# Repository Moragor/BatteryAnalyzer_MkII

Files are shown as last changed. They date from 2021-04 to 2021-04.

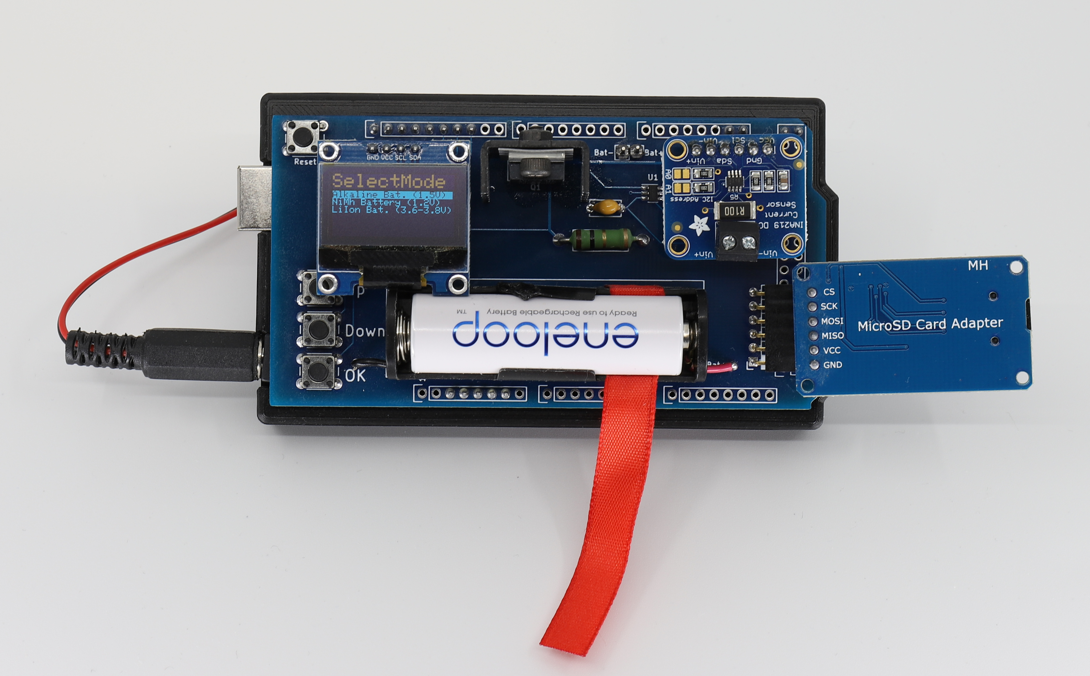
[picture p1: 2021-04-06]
pictures/Bat_mk2_1.JPG

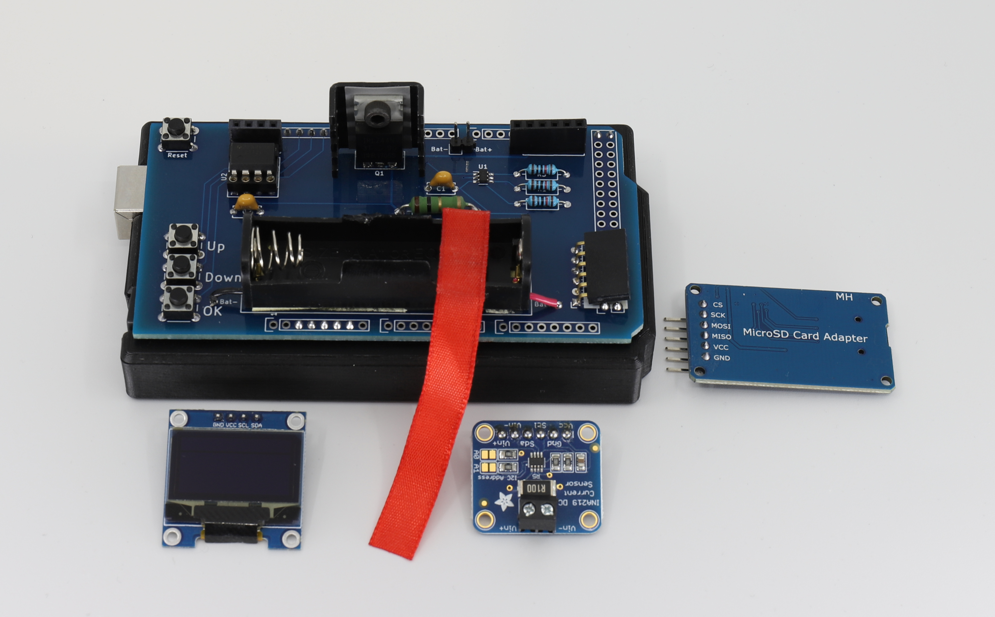
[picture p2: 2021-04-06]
pictures/Bat_mk2_4.JPG

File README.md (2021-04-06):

# BatteryAnalyzer_MkII
Updated Version of the battery analyzer, now with constant current testing instead of fixed resistors.

## Features:
- Selectable test current
- Support for Alkaline/LiFeS2, NiMh and Li-Ion/LiPo (1S) batteries
- Optional datalogging for voltage, current, power, capacity and energy with .csv output on microSD card

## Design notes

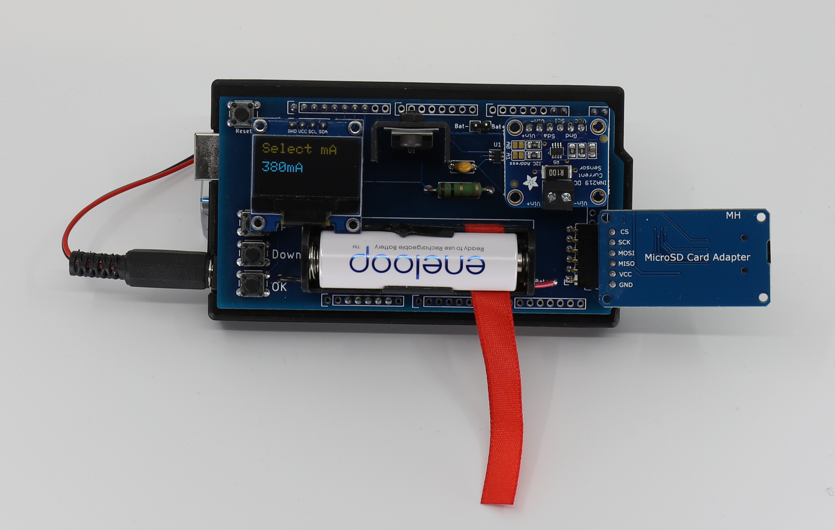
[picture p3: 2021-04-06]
pictures/Bat_mk2_2.JPG

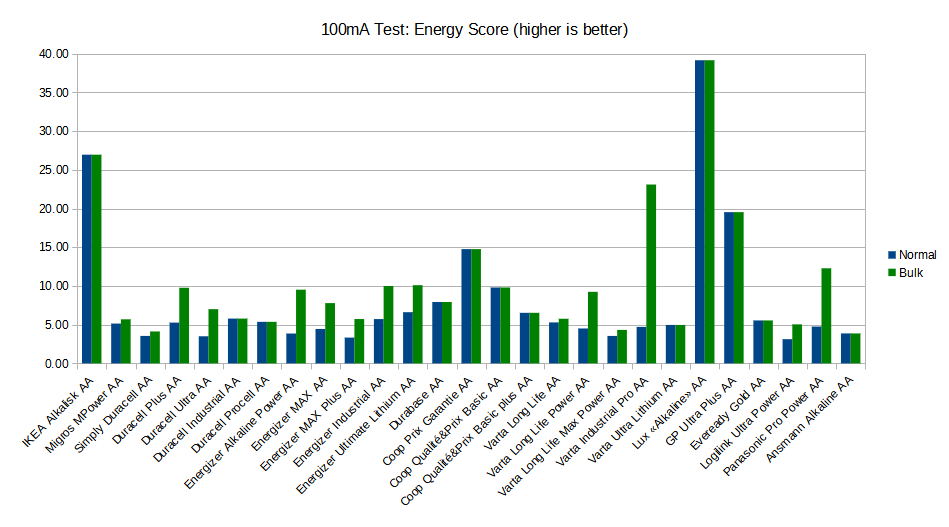
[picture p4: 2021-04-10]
tables and graphs/100mA_Score.png

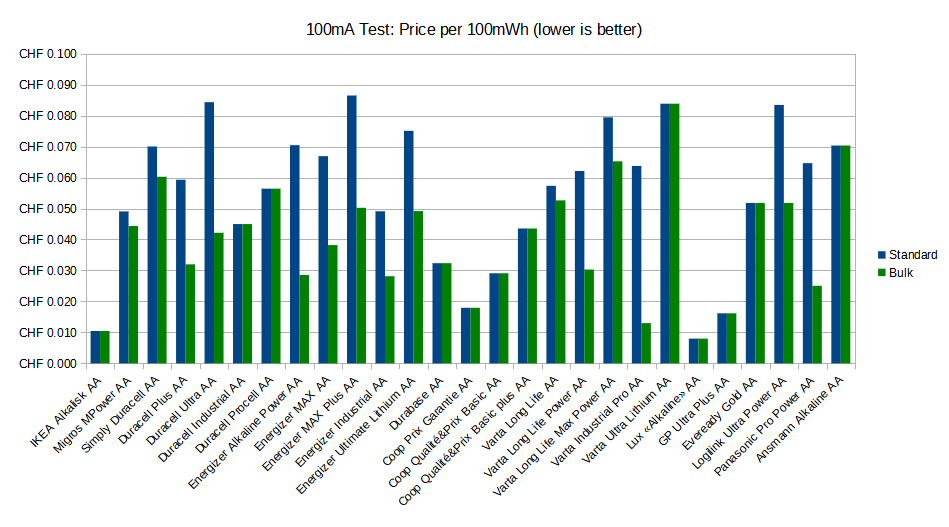
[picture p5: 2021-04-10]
tables and graphs/100mA_PpmWh.png

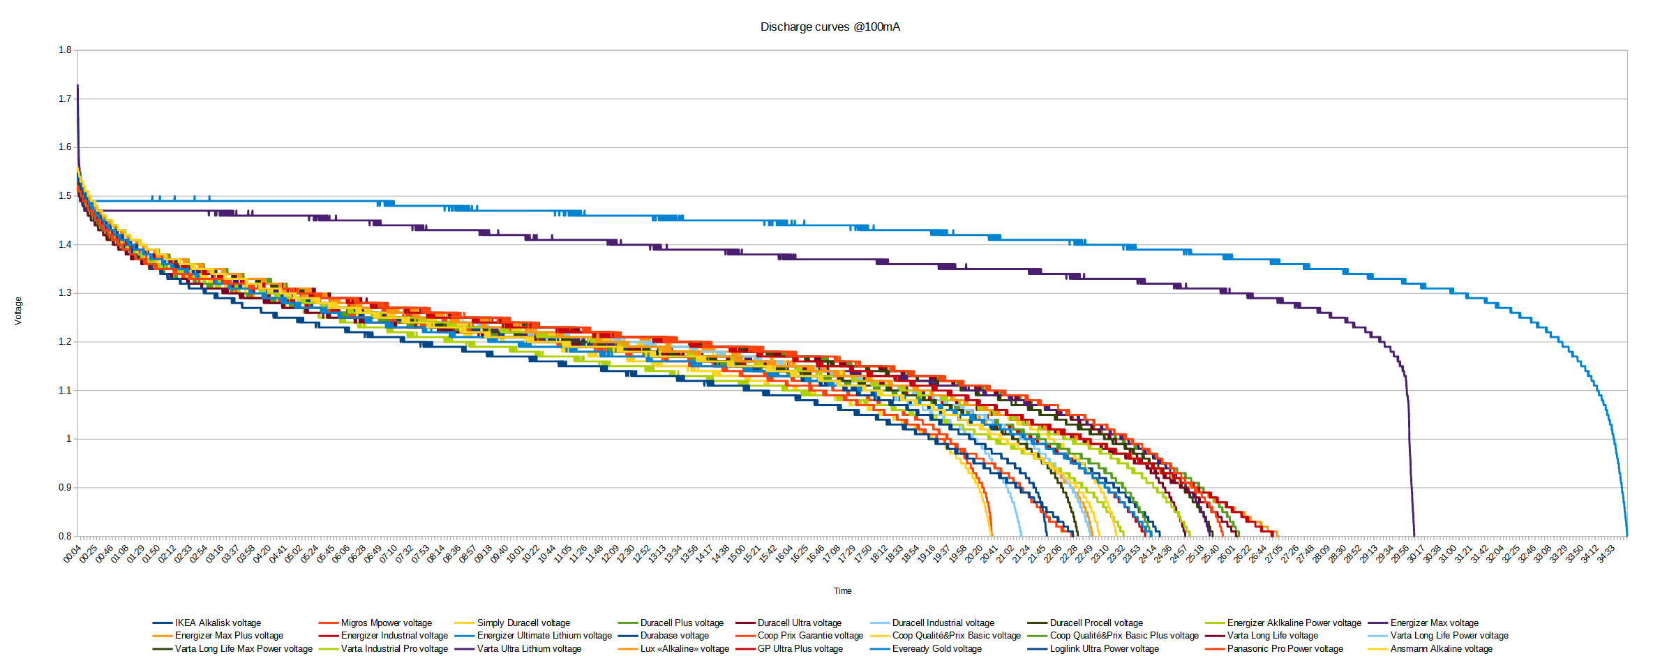
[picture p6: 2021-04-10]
tables and graphs/Discharge_curve_100mA.png

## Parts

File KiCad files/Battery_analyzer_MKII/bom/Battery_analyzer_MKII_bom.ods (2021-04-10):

Reference | Quantity | Value | Footprint | MPN | Digikey part number | Link
BT1 | 1 | AA_Bat_holder | MyComponents:AA_Battery_holder_L57mm_W17mm | 2461 | 36-2461-ND | https://www.digikey.ch/product-detail/de/keystone-electronics/2461/36-2461-ND/303810
C1 C2 | 2 | 1.0µF | MyComponents:C_Disc_D5.5mm_W2.7mm_P5.5mm | C333C105K5R5TA | 399-13915-ND | https://www.digikey.ch/product-detail/de/kemet/C333C105K5R5TA/399-13915-ND/6562326
J1 | 1 | Ext_bat_in | Connector_PinHeader_2.54mm:PinHeader_1x02_P2.54mm_Vertical | PREC002SAAN-RC | S1012EC-02-ND | https://www.digikey.ch/product-detail/de/sullins-connector-solutions/PREC002SAAN-RC/S1012EC-02-ND/2774852
J2 | 1 | OLED | Connector_PinSocket_2.54mm:PinSocket_1x04_P2.54mm_Vertical | SSW-104-01-T-S | SAM1213-04-ND | https://www.digikey.ch/product-detail/de/samtec-inc/SSW-104-01-T-S/SAM1213-04-ND/1112301
J3 | 1 | SD | Connector_PinSocket_2.54mm:PinSocket_1x06_P2.54mm_Horizontal | SSQ-106-02-T-S-RA | SAM1195-06-ND | https://www.digikey.ch/product-detail/de/samtec-inc/SSQ-106-02-T-S-RA/SAM1195-06-ND/1111406
J4 | 1 | INA291 | Connector_PinSocket_2.54mm:PinSocket_1x06_P2.54mm_Vertical | RS1-06-G | 2057-RS1-06-G-ND | https://www.digikey.ch/product-detail/de/adam-tech/RS1-06-G/2057-RS1-06-G-ND/9832050
P1 | 1 | Power | Connector_PinHeader_2.54mm:PinHeader_1x08_P2.54mm_Vertical | PH1-08-UA | 2057-PH1-08-UA-ND | https://www.digikey.ch/product-detail/de/adam-tech/PH1-08-UA/2057-PH1-08-UA-ND/9830442
P2 P3 | 2 | Analog | Connector_PinHeader_2.54mm:PinHeader_1x08_P2.54mm_Vertical | PH1-08-UA | 2057-PH1-08-UA-ND | https://www.digikey.ch/product-detail/de/adam-tech/PH1-08-UA/2057-PH1-08-UA-ND/9830442
P4 | 1 | Digital | Connector_PinHeader_2.54mm:PinHeader_2x18_P2.54mm_Vertical | PREC018DAAN-RC | S2012EC-18-ND | https://www.digikey.ch/product-detail/de/sullins-connector-solutions/PREC018DAAN-RC/S2012EC-18-ND/2774876
P5 | 1 | PWM | Connector_PinHeader_2.54mm:PinHeader_1x10_P2.54mm_Vertical | PH1-10-UA | 2057-PH1-10-UA-ND | https://www.digikey.ch/product-detail/de/adam-tech/PH1-10-UA/2057-PH1-10-UA-ND/9830653
P6 | 1 | PWM | Connector_PinHeader_2.54mm:PinHeader_1x08_P2.54mm_Vertical | PH1-08-UA | 2057-PH1-08-UA-ND | https://www.digikey.ch/product-detail/de/adam-tech/PH1-08-UA/2057-PH1-08-UA-ND/9830442
P7 | 1 | Communication | Connector_PinHeader_2.54mm:PinHeader_1x08_P2.54mm_Vertical | PH1-08-UA | 2057-PH1-08-UA-ND | https://www.digikey.ch/product-detail/de/adam-tech/PH1-08-UA/2057-PH1-08-UA-ND/9830442
Q1 | 1 | IRLZ44N | Package_TO_SOT_THT:TO-220-3_Vertical | IRLZ44NPBF | IRLZ44NPBF-ND | https://www.digikey.ch/product-detail/de/infineon-technologies/IRLZ44NPBF/IRLZ44NPBF-ND/811808
R1 R2 R3 | 3 | 10k | Resistor_THT:R_Axial_DIN0207_L6.3mm_D2.5mm_P10.16mm_Horizontal | MFR-25FBF52-10K | 10.0KXBK-ND | https://www.digikey.ch/product-detail/de/yageo/MFR-25FBF52-10K/10-0KXBK-ND/13219
R4 | 1 | 1R 2W | Resistor_THT:R_Axial_DIN0411_L9.9mm_D3.6mm_P15.24mm_Horizontal | RSMF2JT1R00 | RSMF2JT1R00CT-ND | https://www.digikey.ch/product-detail/de/stackpole-electronics-inc/RSMF2JT1R00/RSMF2JT1R00CT-ND/2021849
SW1 | 1 | UpButton | Button_Switch_THT:SW_PUSH_6mm_H5mm | 1825910-6 | 450-1650-ND | https://www.digikey.ch/product-detail/de/te-connectivity-alcoswitch-switches/1825910-6/450-1650-ND/1632536
SW2 | 1 | DnButton | Button_Switch_THT:SW_PUSH_6mm_H5mm | 1825910-6 | 450-1650-ND | https://www.digikey.ch/product-detail/de/te-connectivity-alcoswitch-switches/1825910-6/450-1650-ND/1632536
SW3 | 1 | OkButton | Button_Switch_THT:SW_PUSH_6mm_H5mm | 1825910-6 | 450-1650-ND | https://www.digikey.ch/product-detail/de/te-connectivity-alcoswitch-switches/1825910-6/450-1650-ND/1632536
SW4 | 1 | ResetButton | Button_Switch_THT:SW_PUSH_6mm_H5mm | 1825910-6 | 450-1650-ND | https://www.digikey.ch/product-detail/de/te-connectivity-alcoswitch-switches/1825910-6/450-1650-ND/1632536
U1 | 1 | MCP4725A0T-E_CH | Package_TO_SOT_SMD:SOT-23-6_Handsoldering | MCP4725A0T-E/CH | MCP4725A0T-E/CHCT-ND | https://www.digikey.ch/product-detail/de/microchip-technology/MCP4725A0T-E-CH/MCP4725A0T-E-CHCT-ND/1817328
U2 | 1 | TLV2372 | Package_DIP:DIP-8_W7.62mm_Socket | TLV2372IP | 296-12219-5-ND | https://www.digikey.ch/products/de/integrated-circuits-ics/linear-amplifiers-instrumentation-op-amps-buffer-amps/687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
U2 | 1 | 8-pin IC socket (optional) | Package_DIP:DIP-8_W7.62mm_Socket | ICS-308-T | 2057-ICS-308-T-ND | https://www.digikey.ch/product-detail/de/adam-tech/ICS-308-T/2057-ICS-308-T-ND/9829299
 | 1 | 0.96inch OLED screen |  |  |  | https://www.aliexpress.com/item/32643950109.html
 | 1 | INA291 module |  | 904 | 1528-1168-ND | https://www.digikey.ch/product-detail/de/adafruit-industries-llc/904/1528-1168-ND/5353628
 | 1 | MicroSD card adapter |  |  |  | https://www.aliexpress.com/item/4000002592780.html
 | 1 | mMicro SD card |  |  |  | https://www.amazon.com/-/de/dp/B073K14CVB?psc=1
 | 1 | Arduino Mega 2560 |  | A000067 | 1050-1018-ND | https://www.digikey.ch/product-detail/de/arduino/A000067/1050-1018-ND/2639006
 | 1 | TO-220 Heatsink |  | 274-1AB | 345-1023-ND | https://www.digikey.ch/product-detail/de/wakefield-vette/274-1AB/345-1023-ND/340321

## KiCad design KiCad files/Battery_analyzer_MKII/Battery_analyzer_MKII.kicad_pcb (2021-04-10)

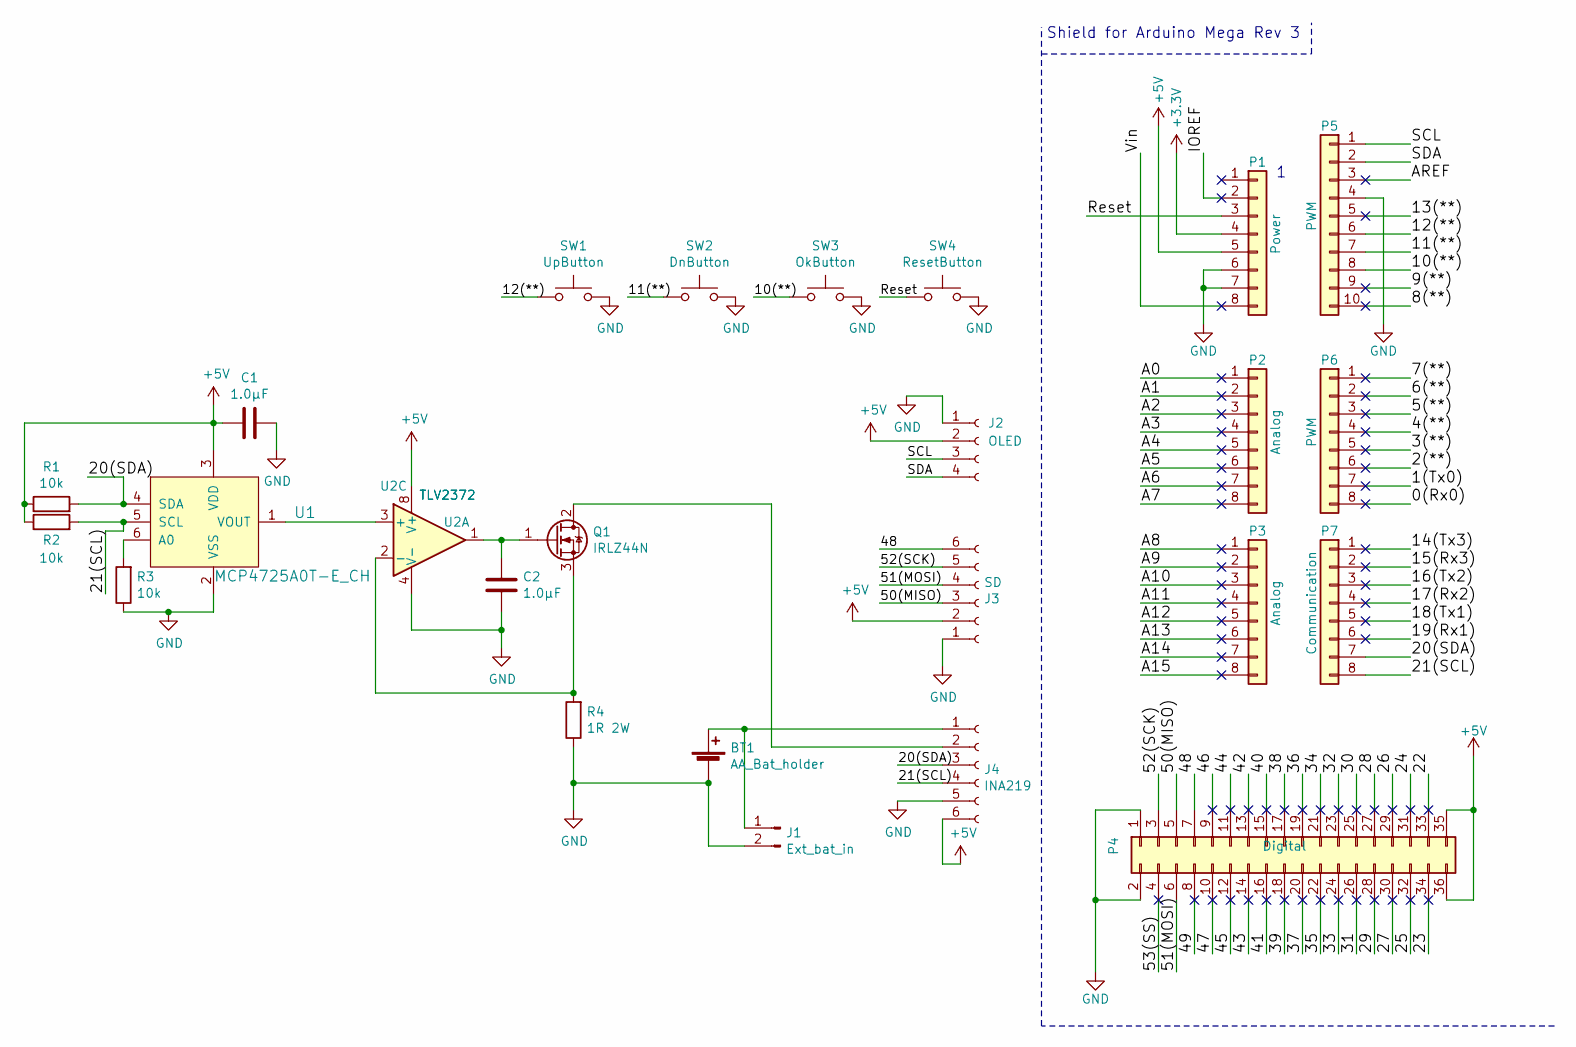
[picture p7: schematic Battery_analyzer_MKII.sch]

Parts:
BT1: AA_Bat_holder; AA_Battery_holder_L57mm_W17mm
C1, C2: 1.0µF; C_Disc_D5.5mm_W2.7mm_P5.5mm
J1: Ext_bat_in; PinHeader_1x02_P2.54mm_Vertical
J2: OLED; PinSocket_1x04_P2.54mm_Vertical
J3: SD; PinSocket_1x06_P2.54mm_Horizontal
J4: INA219; PinSocket_1x06_P2.54mm_Vertical
P1: Power; PinHeader_1x08_P2.54mm_Vertical
P2, P3: Analog; PinHeader_1x08_P2.54mm_Vertical
P4: Digital; PinHeader_2x18_P2.54mm_Vertical
P5: PWM; PinHeader_1x10_P2.54mm_Vertical
P6: PWM; PinHeader_1x08_P2.54mm_Vertical
P7: Communication; PinHeader_1x08_P2.54mm_Vertical
Q1: IRLZ44N; TO-220-3_Vertical
R1, R2, R3: 10k; R_Axial_DIN0207_L6.3mm_D2.5mm_P10.16mm_Horizontal
R4: 1R 2W; R_Axial_DIN0411_L9.9mm_D3.6mm_P15.24mm_Horizontal
SW1: UpButton; SW_PUSH_6mm_H5mm
SW2: DnButton; SW_PUSH_6mm_H5mm
SW3: OkButton; SW_PUSH_6mm_H5mm
SW4: ResetButton; SW_PUSH_6mm_H5mm
U1: MCP4725A0T-E_CH; SOT-23-6_Handsoldering; MPN MCP4725A0T-E/CH; Digi-Key_PN MCP4725A0T-E/CHCT-ND
U2: TLV2372; DIP-8_W7.62mm_Socket

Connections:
+3V3: P1.4
+5V: C1.2, J2.2, J3.2, J4.6, P1.5, P4.35, P4.36, R1.1, R2.1, U1.3 (VDD), U2.8 (V+)
/0(Rx0): P6.8
/1(Tx0): P6.7
/2(**): P6.6
/3(**): P6.5
/4(**): P6.4
/5(**): P6.3
/6(**): P6.2
/7(**): P6.1
/8(**): P5.10
/9(**): P5.9
/10(**): P5.8, SW3.1
/11(**): P5.7, SW2.1
/12(**): P5.6, SW1.1
/13(**): P5.5
/14(Tx3): P7.1
/15(Rx3): P7.2
/16(Tx2): P7.3
/17(Rx2): P7.4
/18(Tx1): P7.5
/19(Rx1): P7.6
/20(SDA): J4.3, P7.7, R1.2, U1.4 (SDA)
/21(SCL): J4.4, P7.8, R2.2, U1.5 (SCL)
/22: P4.33
/23: P4.34
/24: P4.31
/25: P4.32
/26: P4.29
/27: P4.30
/28: P4.27
/29: P4.28
/30: P4.25
/31: P4.26
/32: P4.23
/33: P4.24
/34: P4.21
/35: P4.22
/36: P4.19
/37: P4.20
/38: P4.17
/39: P4.18
/40: P4.15
/41: P4.16
/42: P4.13
/43: P4.14
/44: P4.11
/45: P4.12
/46: P4.9
/47: P4.10
/48: J3.6, P4.7
/49: P4.8
/50(MISO): J3.3, P4.5
/51(MOSI): J3.4, P4.6
/52(SCK): J3.5, P4.3
/53(SS): P4.4
/A0: P2.1
/A1: P2.2
/A2: P2.3
/A3: P2.4
/A4: P2.5
/A5: P2.6
/A6: P2.7
/A7: P2.8
/A8: P3.1
/A9: P3.2
/A10: P3.3
/A11: P3.4
/A12: P3.5
/A13: P3.6
/A14: P3.7
/A15: P3.8
/AREF: P5.3
/IOREF: P1.2
/Reset: P1.3, SW4.1
/SCL: J2.3, P5.1
/SDA: J2.4, P5.2
/Vin: P1.8
GND: BT1.2 (-), C1.1, C2.1, J1.2, J2.1, J3.1, J4.5, P1.6, P1.7, P4.1, P4.2, P5.4, R3.1, R4.1, SW1.2, SW2.2, SW3.2, SW4.2, U1.2 (VSS), U2.4 (V-)
unnamed: BT1.1 (+), J1.1, J4.1
unnamed: C2.2, Q1.1 (G), U2.1
unnamed: J4.2, Q1.2 (D)
unnamed: Q1.3 (S), R4.2, U2.2 (-)
unnamed: R3.2, U1.6 (A0)
unnamed: U1.1 (VOUT), U2.3 (+)

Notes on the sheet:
Shield for Arduino Mega Rev 3

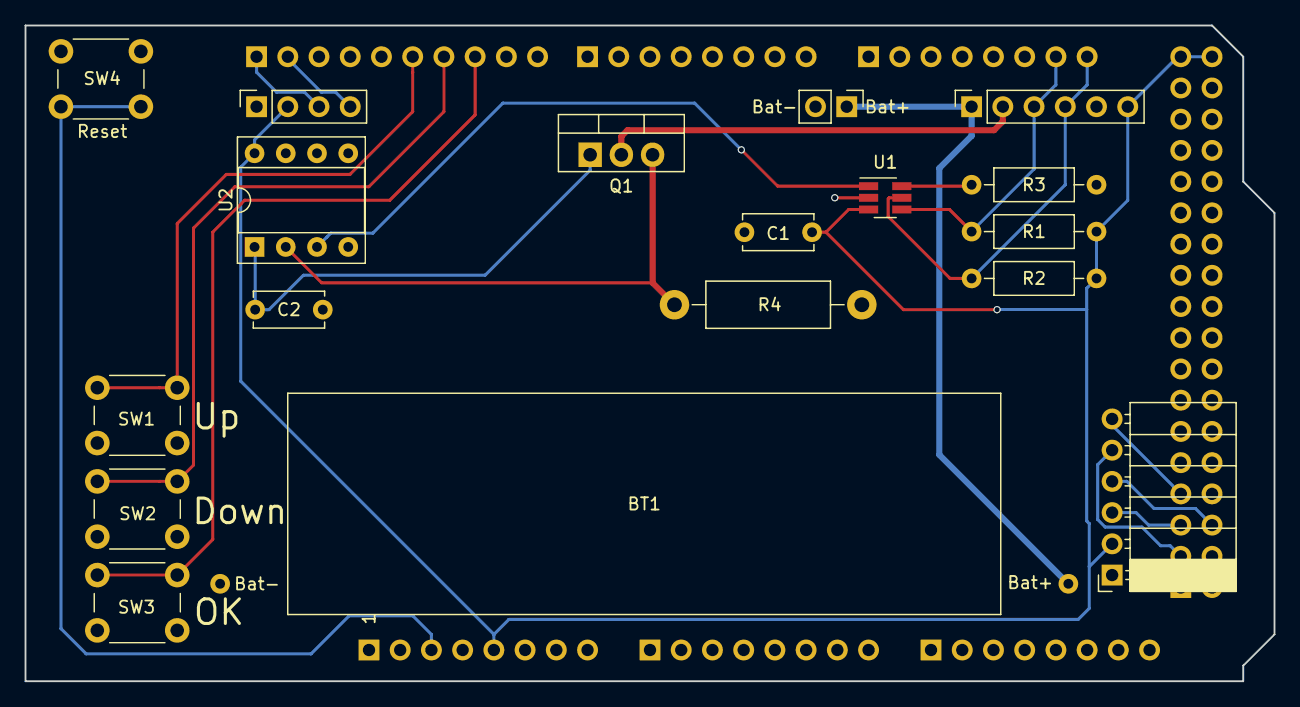
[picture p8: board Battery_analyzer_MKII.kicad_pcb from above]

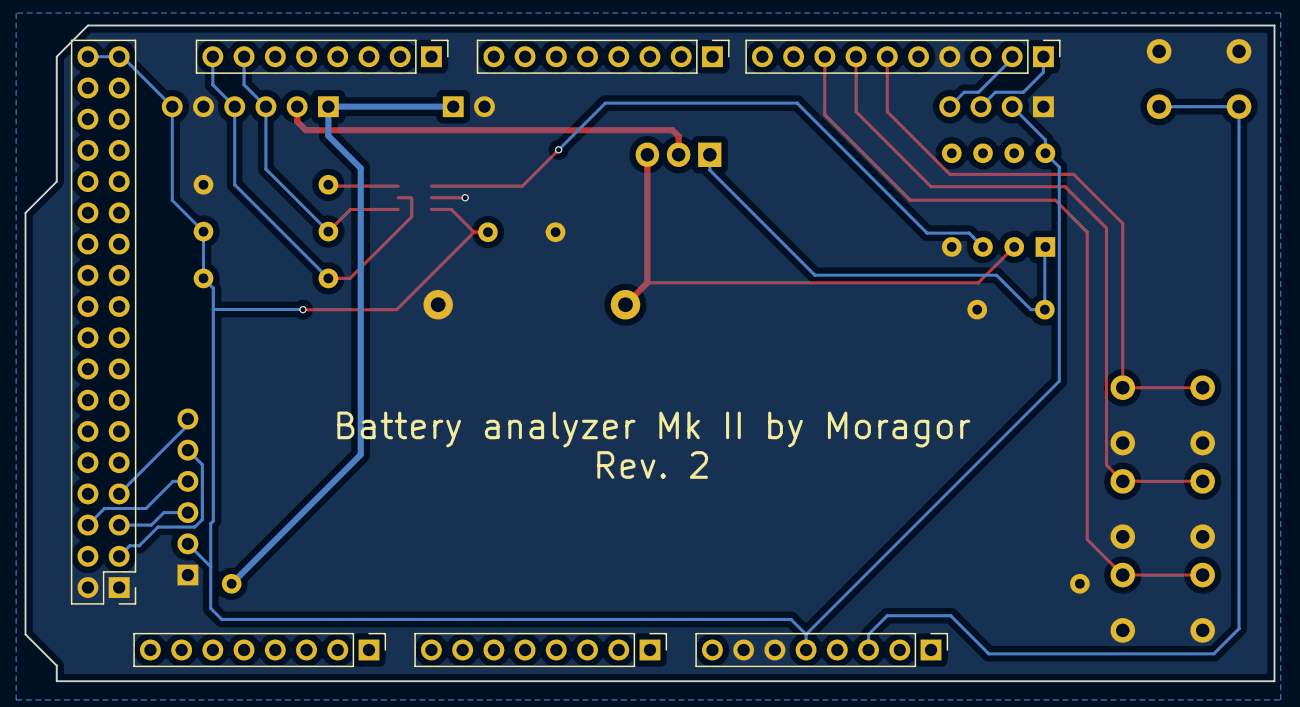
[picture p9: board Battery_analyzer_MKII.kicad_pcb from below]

Board: 2 copper layers, 101.6 x 53.3 mm, 25 parts (7 on the bottom side), 20 nets.

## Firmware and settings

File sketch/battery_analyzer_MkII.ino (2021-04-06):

//Author: Moragor
//Version: 1.0.1
//Created: 05-May-2020
//Last edited: 06-Mar-2021
//License: MIT license (X11, see bottom)


#include <Wire.h>
#include <SPI.h>
#include <SD.h>
#include <Adafruit_INA219.h>
#include <Adafruit_SSD1306.h>
#include <Adafruit_MCP4725.h>

#define SCREEN_WIDTH 128        // OLED display width, in pixels
#define SCREEN_HEIGHT 64        // OLED display height, in pixels
#define buttonPinUp 12
#define buttonPinDn 11
#define buttonPinOk 10
#define logInterval  1000       //The time between measurements
#define sdInterval 15000        //The time between datapoints collected for the SD card
#define syncInterval 180000     //How often data will be written to the SD card
#define SD_CS 48
float current_mA = 0;
float power_mW = 0;
float loadvoltage = 0;
float capacity_mAh = 0;
float capacity_mWh = 0;
unsigned long prevMillis = 0;
unsigned long startMillis;
byte sPassed = 0;
byte minPassed = 0;
byte hPassed = 0;
float endVoltage;
byte mode = 1;
int amp = 300;
unsigned long syncTime = 0;
unsigned long sdTime = 0;
bool sdMissing = 0;

Adafruit_MCP4725 dac;
Adafruit_SSD1306 display(SCREEN_WIDTH, SCREEN_HEIGHT, &Wire);
Adafruit_INA219 ina219;
File logfile;

void setup()
{
  pinMode(buttonPinUp, INPUT_PULLUP);
  pinMode(buttonPinDn, INPUT_PULLUP);
  pinMode(buttonPinOk, INPUT_PULLUP);
  display.begin(SSD1306_SWITCHCAPVCC, 0x3C);
  dac.begin(0x60);
  dac.setVoltage(0, false);
  if (!SD.begin(SD_CS)) {
    sdMissing = 1;            //Checking if a SD card is present
  }
  ina219.begin();     // Initialize the INA219. By default the initialization will use the largest range (32V, 2A).
  // To use a slightly lower 32V, 1A range (higher precision on amps):
  ina219.setCalibration_32V_1A();
  // Or to use a lower 16V, 400mA range (higher precision on volts and amps):
  //ina219.setCalibration_16V_400mA();
  testMode();     //Starting the mode selection subroutine (I always wanted to use that word :D)
  testAmp();      //Starting the test current selection
  testBattery();  //Starting the battery test
}

void loop()
{
  //nuffing
}

void testMode()
{
  bool buttonState1;
  bool lastButtonState1 = HIGH;
  unsigned long lastDebounceTime1 = 0;
  bool buttonState2;
  bool lastButtonState2 = HIGH;
  unsigned long lastDebounceTime2 = 0;
  while (1) {     //creates an infinite loop which is exited with "break"
    modeDisplay();      //See the modeDisplay function bellow
    if (digitalRead(buttonPinOk) == LOW) {
      while (digitalRead(buttonPinOk) == LOW) {     //No clue how to debounce while switching from one function to another, so I make it on button release
        delay(50);
      }
      if (mode == 1)
      {
        endVoltage = 0.8;     //Alkaline batteries
        break;
      }
      else if (mode == 2)
      {
        endVoltage = 1.0;     //NiMh batteries
        break;
      }
      else
      {
        endVoltage = 2.8;     //LiPo batteries (one cell)
        break;
      }
    }


    bool reading1 = digitalRead(buttonPinUp);
    if (reading1 != lastButtonState1) {
      lastDebounceTime1 = millis();
    }
    if ((millis() - lastDebounceTime1) > 50) {
      if (reading1 != buttonState1) {
        buttonState1 = reading1;
        if (buttonState1 == LOW) {
          mode--;
          if (mode == 0)
          {
            mode = 3;
          }
        }
      }
    }
    lastButtonState1 = reading1;

    bool reading2 = digitalRead(buttonPinDn);
    if (reading2 != lastButtonState2) {
      lastDebounceTime2 = millis();
    }
    if ((millis() - lastDebounceTime2) > 50) {
      if (reading2 != buttonState2) {
        buttonState2 = reading2;
        if (buttonState2 == LOW) {
          mode++;
          if (mode >= 4)
          {
            mode = 1;
          }
        }
      }
    }
    lastButtonState2 = reading2;
  }
}

void testAmp()      //In this function the test current is set.
{
  while (1) {     //creates an infinite loop which is exited with "break"
    ampDisplay();      //See the ampDisplay function bellow

    //Ok button
    if (digitalRead(buttonPinOk) == LOW) {      //No debounce needed here, the function ends when the button is pressed.
      break;
    }

    //Up button
    unsigned long tPressed1;
    bool hold1 = 0;
    bool lastButtonState1 = HIGH;
    if (digitalRead(buttonPinUp) == LOW) {
      lastButtonState1 = LOW;
      tPressed1 = millis();
      delay(5);                                      //Debounce delay
      while (digitalRead(buttonPinUp) == LOW) {       //While the button is held this loop repeats.
        while (digitalRead(buttonPinUp) == LOW && millis() - tPressed1 >= 750) {      //This loop goes active when the button is held for 750ms.
          hold1 = 1;      //Shows that the "auto" mode was used for later.
          amp += 5;       //While the button is held for 750ms+ the test current raises by 5mA every ~50ms.
          if (amp > 600)  //This if statement limits the max current to 600mA and keeps the power bellow what my MOSFET heatsink can handle when testing a 1S LiPo.
          {
            amp = 600;
          }
          ampDisplay();
          delay(50);
        }
      }
    }
    //When the button is released it gets checked if "auto" mode was used.
    //If not the test current is raised by 5mA.
    //If yes the "auto" indicator is reset and the current isn't raised an additional time.
    if (digitalRead(buttonPinUp) == HIGH && lastButtonState1 == LOW && hold1 == 0) {
      amp += 5;
      if (amp > 600)
      {
        amp = 600;
      }
      lastButtonState1 = HIGH;
    }
    else if (digitalRead(buttonPinUp) == HIGH && lastButtonState1 == LOW && hold1 == 1) {
      hold1 = 0;
      lastButtonState1 = HIGH;
    }

    //Down button, basically the same as the up button.
    unsigned long tPressed2;
    bool hold2 = 0;
    bool lastButtonState2 = HIGH;
    if (digitalRead(buttonPinDn) == LOW) {
      lastButtonState2 = LOW;
      tPressed2 = millis();
      delay(5);
      while (digitalRead(buttonPinDn) == LOW) {
        while (digitalRead(buttonPinDn) == LOW && millis() - tPressed2 >= 750) {
          hold2 = 1;
          amp -= 5;
          if (amp < 100)
          {
            amp = 100;
          }
          ampDisplay();
          delay(50);
        }
      }
    }
    if (digitalRead(buttonPinDn) == HIGH && lastButtonState2 == LOW && hold2 == 0) {
      amp -= 5;
      if (amp < 100)
      {
        amp = 100;
      }
      lastButtonState2 = HIGH;
    }
    else if (digitalRead(buttonPinDn) == HIGH && lastButtonState2 == LOW && hold2 == 1) {
      hold2 = 0;
      lastButtonState2 = HIGH;
    }
  } //main loop
} //function

void testBattery()    //This is the main test function.
{
  int cycleMillis = 0;
  int dacv = 0;
  if (amp < 400) {
    ina219.setCalibration_16V_400mA();      //Using the high precision mode when the test current is low.
  }
  loadvoltage = (ina219.getBusVoltage_V() + (ina219.getShuntVoltage_mV() / 1000));      //This tests if the battery is actually charged enough for the test.
  if (endVoltage >= loadvoltage)
  {
    dac.setVoltage(0, false);
    display.clearDisplay();
    display.setTextSize(2);
    display.setTextColor(WHITE);
    display.setCursor(0, 0);
    display.println();
    display.println(F("  Battery"));
    display.print(F("    low!"));
    display.display();
    return;                     //This exits the testBattery function and starts the empty loop preventing tests on an empty battery.
  }
  else
  {
    if (!sdMissing) {             //The "!" makes something negative. In this case it means "if SD is not missing" or "sdMissing == 0".
      logInit();                  //This function creates a new logfile on the SD card if it's present.
    }
    for (ina219.getCurrent_mA(); ina219.getCurrent_mA() < (amp - 5); dacv++) {      //This ramps up the DAC voltage until the current through the MOSFET is slightly bellow the desired value.
      dac.setVoltage(dacv, false);
    }
    delay(25);
    for (ina219.getCurrent_mA(); ina219.getCurrent_mA() < amp; dacv++) {      //This slowly ramps up the DAC voltage until the desired current through the MOSFET is reached.
      dac.setVoltage(dacv, false);
      delay(25);
    }

    startMillis = millis();     //This records the time the actual test starts.
    prevMillis = startMillis;   //prevMillis is the time the last measuremant was taken
    while (loadvoltage > endVoltage) {
      cycleMillis = millis() - prevMillis;     //cycleMillis is the time the last cycle took
      prevMillis = millis();
      current_mA = ina219.getCurrent_mA();
      loadvoltage = (ina219.getBusVoltage_V() + (ina219.getShuntVoltage_mV() / 1000));
      power_mW = current_mA * loadvoltage;
      capacity_mAh = capacity_mAh + (current_mA * cycleMillis / 3600000.0);     //The capacity is added up durring the test
      capacity_mWh = capacity_mWh + (current_mA * loadvoltage * cycleMillis / 3600000.0);     //3600000 is the number of milliseconds in a hour
      sPassed = ((prevMillis - startMillis) / 1000) % 60;     //For the % operation see https://www.arduino.cc/reference/en/language/structure/arithmetic-operators/remainder/
      minPassed = ((prevMillis - startMillis) / 60000) % 60;
      hPassed = ((prevMillis - startMillis) / 3600000);

      testDisplay();      //This function displays the collected data on the OLED screen
      if ((millis() >= sdTime + sdInterval && !sdMissing) || (sdTime == 0 && !sdMissing)) {     //This writes a datapoint to the SD card every "sdInterval" milliseconds if a card is present. sdTime == 0 is for the very first datapoint at 0 seconds.
        logLog();                                                                               //Initially I recorded a datapoint every cycle, but this lead to an unnecessarily high ammount of datapoints.
        sdTime = millis();
      }
      if (ina219.getCurrent_mA() < (amp - 1)) {
        dacv++;
        dac.setVoltage(dacv, false);
      }
      if (ina219.getCurrent_mA() > (amp + 1)) {
        dacv--;
        dac.setVoltage(dacv, false);
      }

      delay((logInterval - 1) - (millis() % logInterval));      //This little calculation makes sure a cycle always takes the same ammount of time
    }
  }
  if (!sdMissing) {                       //As soon as the end voltage is reached and the while loop ends a last datapoint is recorded if a SD card is present
    logLog();
  }
  dac.setVoltage(0, false);               //"Turn off" the MOSFET to prevent overdischarge
  logfile.close();                        //The logfile on the SD card is saved and closed
  display.setTextSize(1);                 //A text on the OLED indicates the end of the test. The display id not cleared, so the last measurment stays displayed.
  display.setCursor(0, 57);
  display.println(F("Test finished"));
  display.display();
}

void modeDisplay()        //This is the display for the test mode selection (battery type)
{
  display.clearDisplay();
  display.setTextSize(2);
  display.setTextColor(WHITE);
  display.setCursor(0, 0);
  display.println(F("SelectMode"));
  display.setTextSize(1);
  if (mode == 1) {
    display.setTextColor(BLACK, WHITE);     //(BLACK, WHITE) highlights the background of the text to show which mode is selected
  }
  else {
    display.setTextColor(WHITE);
  }
  display.println(F("Alkaline Bat. (1.5V) "));      //With F() the text isn't loaded into ram which is nice if you're short on ram
  if (mode == 2) {
    display.setTextColor(BLACK, WHITE);
  }
  else {
    display.setTextColor(WHITE);
  }
  display.println(F("NiMh Battery (1.2V)  "));
  if (mode == 3) {
    display.setTextColor(BLACK, WHITE);
  }
  else {
    display.setTextColor(WHITE);
  }
  display.println(F("LiIon Bat. (3.6-3.8V)"));
  if (sdMissing) {
    display.setTextColor(WHITE);
    display.setCursor(0, 57);
    display.print(F("No SD card!"));
  }
  display.display();
}

void ampDisplay()        //This is the display for the test current selection
{
  display.clearDisplay();
  display.setTextSize(2);
  display.setTextColor(WHITE);
  display.setCursor(0, 0);
  display.println(F("Select mA"));
  display.setCursor(0, 25);
  display.print(amp );
  display.print("mA");

  if (sdMissing) {
    display.setTextSize(1);
    display.setCursor(0, 57);
    display.print(F("No SD card!"));
  }
  display.display();
}

void testDisplay()                  //This function displays the collected data on the OLED during the actual test
{
  display.clearDisplay();
  display.setTextSize(1);
  display.setTextColor(WHITE);
  display.setCursor(0, 0);
  display.print(F("Capacity "));
  display.print(capacity_mAh);
  display.println(F("mAh"));
  display.print(F("Energy "));
  display.setCursor(54, 8);
  display.print(capacity_mWh);
  display.println(F("mWh"));
  display.print(F("Voltage "));
  display.setCursor(54, 16);
  display.print(loadvoltage);
  display.println(F("V"));
  display.print(F("Current "));
  display.setCursor(54, 24);
  display.print(current_mA);
  display.println(F("mA"));
  display.print(F("Power "));
  display.setCursor(54, 32);
  display.print(power_mW);
  display.println(F("mW"));
  display.print(F("Time "));
  display.setCursor(54, 40);
  display.print(hPassed);
  display.print(F(":"));
  if (minPassed < 10) {             //This adds a leading zero if the value is bellow 10
    display.print(F("0"));
  }
  display.print(minPassed);
  display.print(F(":"));
  if (sPassed < 10) {
    display.print(F("0"));
  }
  display.print(sPassed);
  if (sdMissing) {
    display.setCursor(0, 49);
    display.print(F("No SD card!"));
  }
  display.display();
}

void logInit()
{
  // create a new logfile
  char filename[] = "LOGGER00.CSV";
  for (uint8_t i = 0; i < 100; i++) {
    filename[6] = i / 10 + '0';           //These two lines replace the 00 in LOGGER00.CSV with rising numbers if a file already exists
    filename[7] = i % 10 + '0';           //This is waaaay too complicated for me, so thanks Adafruit.
    if (! SD.exists(filename)) {          // only open a new file if it doesn't exist
      logfile = SD.open(filename, FILE_WRITE);
      break;  // leave the loop!
    }
  }
  logfile.println(F("millis,voltage,current,power,capacity,energy"));     //This writes the first line to the logfile to name the columns
  logfile.flush();        //This command actually saves the data on the SD card
}

void logLog()     //This function saves the collected data on the SD card
{
  logfile.print(prevMillis - startMillis);        // milliseconds since start
  logfile.print(", ");                            //A CSV file is a text file with Comma Separated Values. A spreadsheet program will assign every comma separated value to a new column.
  logfile.print(loadvoltage);
  logfile.print(", ");
  logfile.print(current_mA);
  logfile.print(", ");
  logfile.print(power_mW);
  logfile.print(", ");
  logfile.print(capacity_mAh);
  logfile.print(", ");
  logfile.print(capacity_mWh);

  logfile.println();                              //A line break will start a new row in a spreadsheet

  if ((millis() - syncTime) < syncInterval) return;
  syncTime = millis();
  logfile.flush();
}



/*Copyright (c) 2021 Fabian Hunziker "Moragor"

  Permission is hereby granted, free of charge, to any person obtaining a copy of this software and associated documentation files
  (the "Software"), to deal in the Software without restriction, including without limitation the rights to use, copy, modify, merge,
  publish, distribute, sublicense, and/or sell copies of the Software, and to permit persons to whom the Software is furnished to do
  so, subject to the following conditions:

  The above copyright notice and this permission notice shall be included in all copies or substantial portions of the Software.

  THE SOFTWARE IS PROVIDED "AS IS", WITHOUT WARRANTY OF ANY KIND, EXPRESS OR IMPLIED, INCLUDING BUT NOT LIMITED TO THE WARRANTIES OF
  MERCHANTABILITY, FITNESS FOR A PARTICULAR PURPOSE AND NONINFRINGEMENT. IN NO EVENT SHALL THE AUTHORS OR COPYRIGHT HOLDERS BE LIABLE
  FOR ANY CLAIM, DAMAGES OR OTHER LIABILITY, WHETHER IN AN ACTION OF CONTRACT, TORT OR OTHERWISE, ARISING FROM, OUT OF OR IN CONNECTION
  WITH THE SOFTWARE OR THE USE OR OTHER DEALINGS IN THE SOFTWARE. */
